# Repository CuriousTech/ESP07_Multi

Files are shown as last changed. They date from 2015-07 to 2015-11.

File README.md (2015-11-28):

# ESP07_Multi  Experiment board.  Multi-use  

I2C OLED and DHT-22 (back if regulator stays cool, otherwise extended facing top)  

BOM will have a few voltage regulator options chosen by voltage range, drop out, quiescent and support component cross compatibility.  The OLED can tax the 300mA regulator.

ADC option: Photocell or source voltage read  
IO0 could have been used for something (well, next time)  
IO12 option: button or PNP sink  
IO13 option: LED or PNP (or both)  
IO14 only raw I/O pad  
IO16 option: deepSleep, raw I/O or button.  (Note: IO16 has no internal pullup for button)

Actual Device  

iot.php - simple script for saving data from a device.  
Create a directoy named "iot" in the same directory as iot.php  
A POST to this will create an XML formatted file using 'name' as the filename.xml  
All fields will be written as XML values overwriting the older file, and appended to filename.txt as JS array data.  
A GET /iot.php?name=file will return the data in the xml file.

chart.php?name=filename will draw a chart.  This one is designed for date, temp, rh, volts.

fwdip.php?name=myDevice&port=number will create server/iot/myDevice.php with script to forward all GET data to IP of device that created it.  The global IP and current date/time are also returned to the creator.

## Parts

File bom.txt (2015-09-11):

ESP-07
OLED    	 0.96" I2C
DHT-22
3V3R        MCP1824ST-3302E/DB (6V 300mA 0.2Vdo)
            MCP1825S-3302E/DB (6V 500mA 0.21Vdo)
            TC1262-3.3VDBTR (6V 500mA 0.3Vdo)
            MCP1755T-3302E/DC (16V 300mA 0.5Vdo)
            MIC2920A-3.3WS TR (26V 400mA 0.75Vdo) Change C1 to 10uF.

Q1,Q2       SOT-23 General purpose PNP or P-Channel FET
R1-R4       10K 0805
R5	1K 0805
R6          4K7 0805
R7	330 0805
LED1	0805
C1,C2,C3    1uF 0805
CDS         4mm pitch
FLASH,RESET 4x2mm butttons
PWR,SER     2-pin 0.1" header
Top buttons 4x4mm

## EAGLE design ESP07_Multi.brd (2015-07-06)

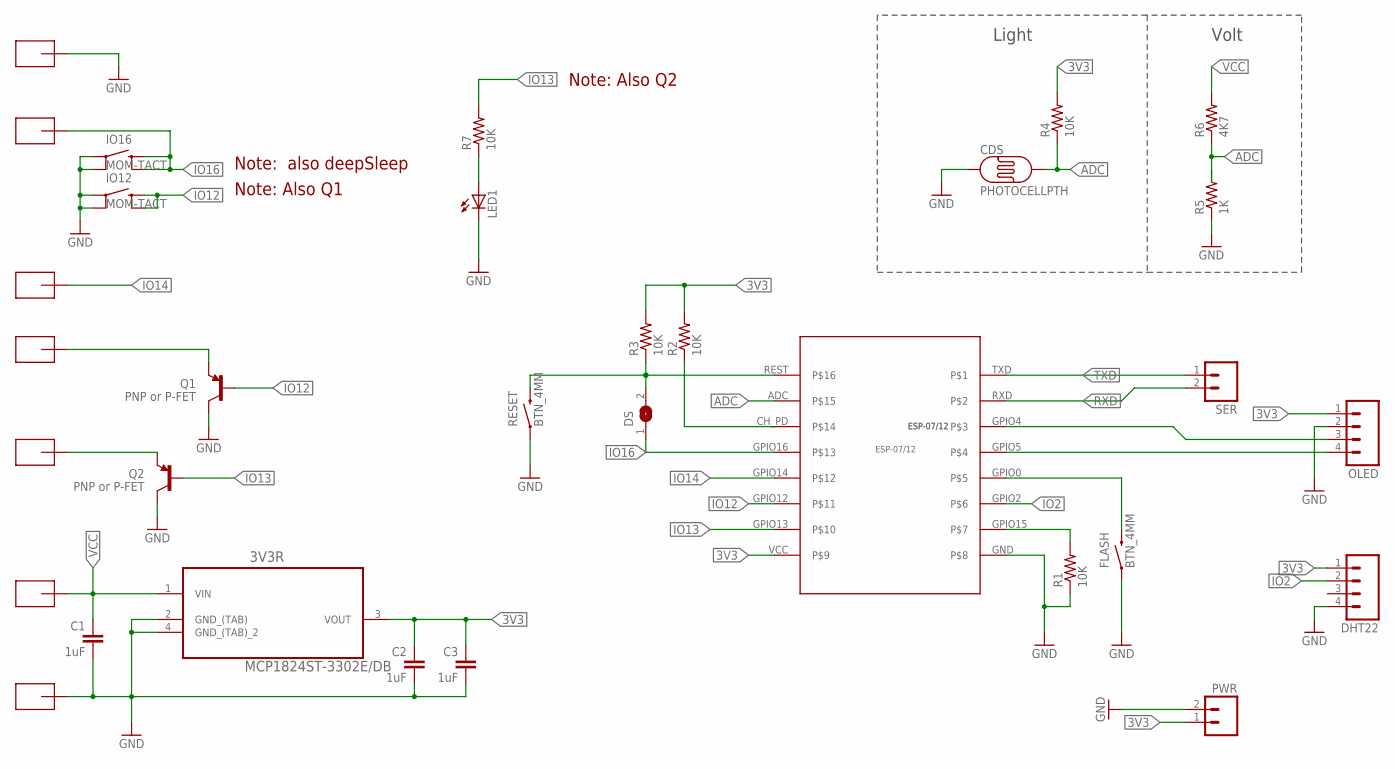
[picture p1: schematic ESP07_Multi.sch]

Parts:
3V3R: MCP1824ST-3302E/DB; SOT230P700X180-4N
C1, C2, C3: 1uF; 0805-CAP
CDS: PHOTOCELLPTH; PHOTOCELL
DHT22: M04PTH; 1X04
DS: SJ
FLASH: BTN_4MM
IO12, IO16: MOM-TACT; TACTILE-SMD
LED1: LEDCHIPLED_0805; CHIPLED_0805
OLED: M04PTH; 1X04
PWR: M02PTH; 1X02
Q1, Q2: PNP or P-FET; SOT23-3
R1, R2, R3, R4, R7: 10K; 0805
R5: 1K; 0805
R6: 4K7; 0805
RESET: BTN_4MM
SER: M02PTH; 1X02
U$1: ESP-07/12
U$2, U$3, U$4, U$5, U$6, U$7, U$8: SMD-PAD-SM; SMD-PAD3

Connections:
3V3: 3V3R.3 (VOUT), C2.1, C3.1, DHT22.1, OLED.1, PWR.1, R2.2, R3.2, R4.2, U$1.VCC
ADC: CDS.2, R4.1, R5.2, R6.1, U$1.ADC
GND: 3V3R.2 (GND_(TAB)), 3V3R.4 (GND_(TAB)_2), C1.2, C2.2, C3.2, CDS.1, DHT22.4, FLASH.1, IO12.1, IO12.2 (3), IO16.1, IO16.2 (3), LED1.C, OLED.2, PWR.2, Q1.3 (C), Q2.3 (C), R1.1, R5.1, RESET.1, U$1.GND, U$2.P$1, U$5.P$1
IO2: DHT22.2, U$1.GPIO2
IO12: IO12.3 (2), IO12.4, Q1.1 (B), U$1.GPIO12
IO13: Q2.1 (B), R7.2, U$1.GPIO13
IO14: U$1.GPIO14, U$4.P$1
IO16: DS.1, IO16.3 (2), IO16.4, U$1.GPIO16, U$6.P$1
unnamed: LED1.A, R7.1
unnamed: OLED.3, U$1.GPIO4
unnamed: Q2.2 (E), U$8.P$1
unnamed: Q1.2 (E), U$7.P$1
unnamed: R1.2, U$1.GPIO15
unnamed: OLED.4, U$1.GPIO5
unnamed: FLASH.2, U$1.GPIO0
unnamed: R2.1, U$1.CH_PD
unnamed: DS.2, R3.1, RESET.2, U$1.REST
RXD: SER.2, U$1.RXD
TXD: SER.1, U$1.TXD
VCC: 3V3R.1 (VIN), C1.1, R6.2, U$3.P$1

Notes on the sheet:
Volt
Light
Note: also deepSleep
Note: Also Q1
Note: Also Q2

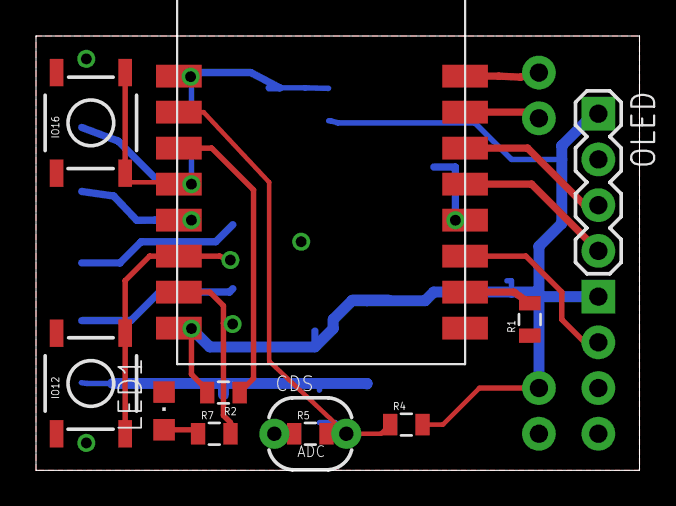
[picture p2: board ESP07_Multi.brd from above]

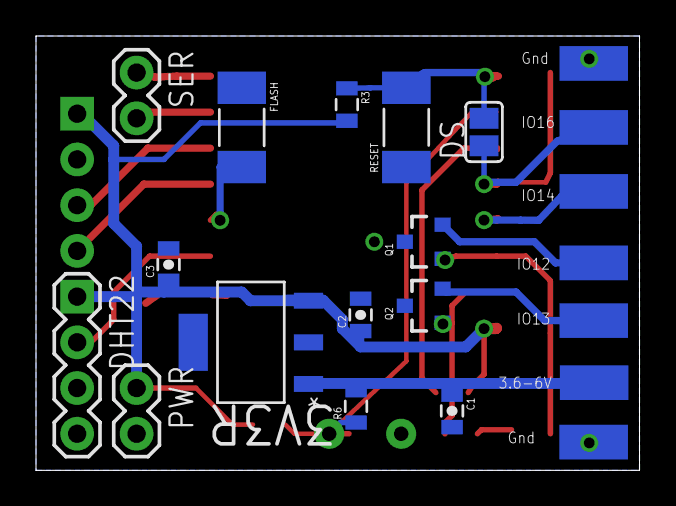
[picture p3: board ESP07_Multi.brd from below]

Board: 2 copper layers, 33.5 x 24.1 mm, 32 parts (21 on the bottom side), 20 nets.

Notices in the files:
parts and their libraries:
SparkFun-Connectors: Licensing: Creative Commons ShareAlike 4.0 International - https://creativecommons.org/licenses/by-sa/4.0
